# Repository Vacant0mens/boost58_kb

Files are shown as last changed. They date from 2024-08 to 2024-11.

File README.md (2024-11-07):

# boost58_kb
 
This layout was given this name because its shape looks similar to the boost arrows in racetrack video games.

# Introduction
I designed this board because I couldn't find any options that fit my requirements for a custom key board, which were:
1. completely reversible circuit board (for a split keyboard)
2. two-way UART communication between the two halves
3. compatible with Kailh Choch v2 switches (with v1 backward compatability)
4. hotswap switch sockets
5. staggered column layout (including a stagger for the outer-pinky column, and inner-index column)
6. 4 finger rows, plus only one thumb row
7. per-key and underglow RGB lights
8. anti-ghosting diodes
9.  promicro-style MCU
10. at least 1 rotary encoder per-side
11. reset button
12. power switch (optional)

I designed this with the intention of making it my dream keyboard, but also available and accessible to others. I am open to suggestions and PR's.

# Build Progress

## v0.1
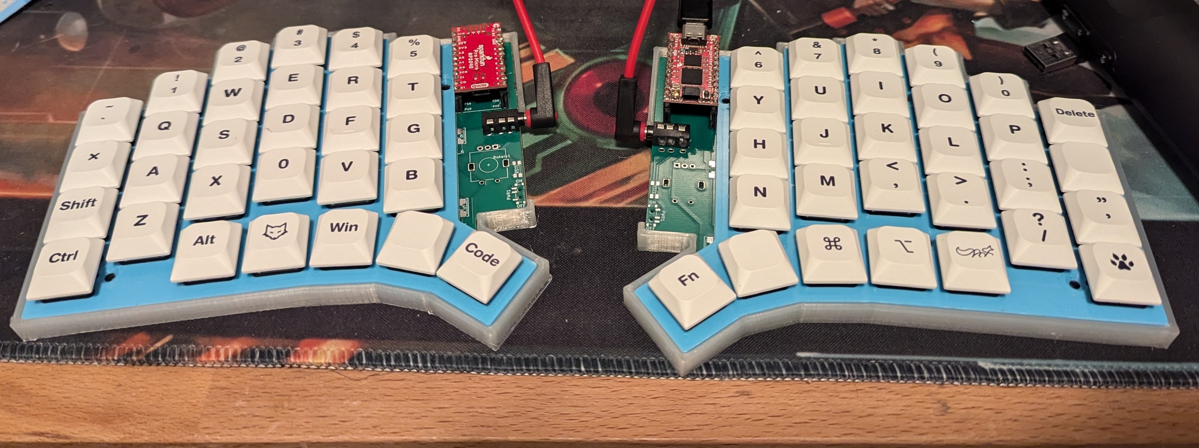
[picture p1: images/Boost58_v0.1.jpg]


## Original Top Layout
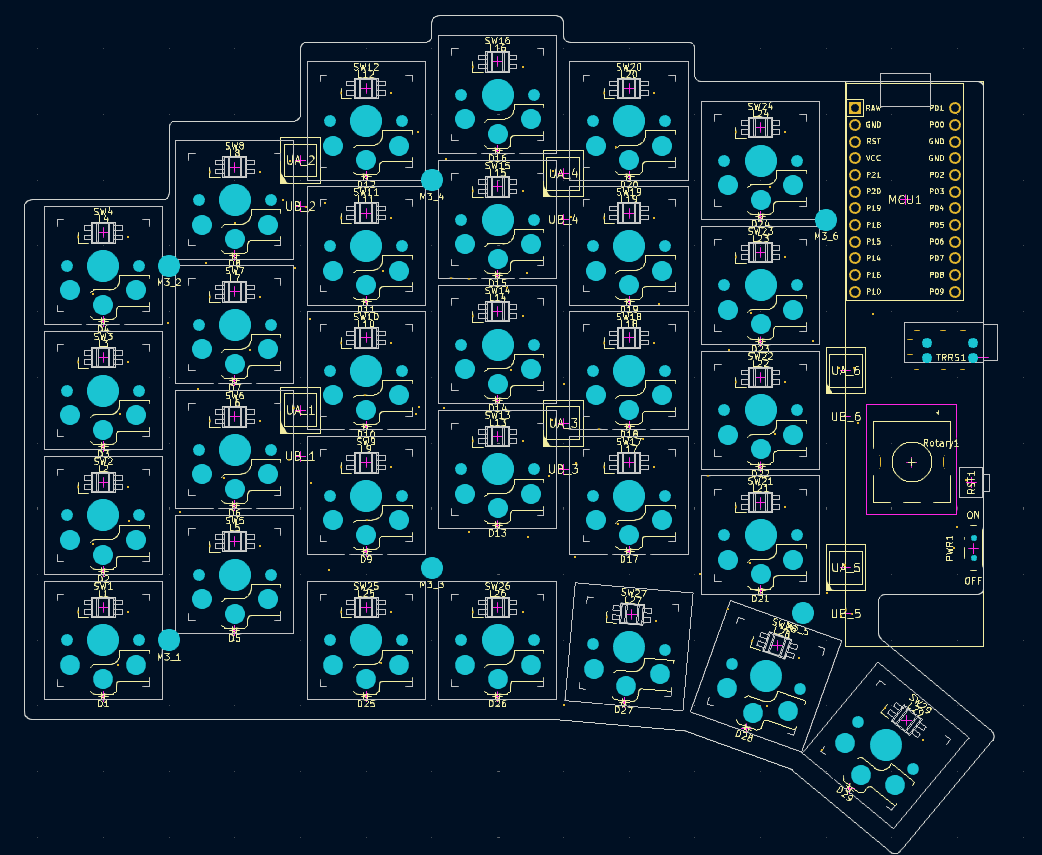
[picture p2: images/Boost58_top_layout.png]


# Thanks
Thanks to [ergogen](https://github.com/ergogen/ergogen) for the base software to be able to create this, and [ceoloide](https://github.com/ceoloide/ergogen-footprints) for the footprints and examples.

# Buy Me a Coffee
[@Vacant0mens](https://buymeacoffee.com/vacan0mens)

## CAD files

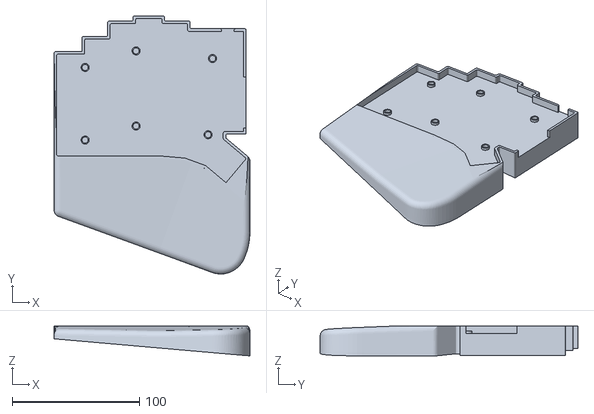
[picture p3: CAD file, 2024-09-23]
ergogen/output/pcbs/Steps and STLs/FullCase_LoweredAngle+AttachedRest.stl
153.7 x 202.6 x 23.4

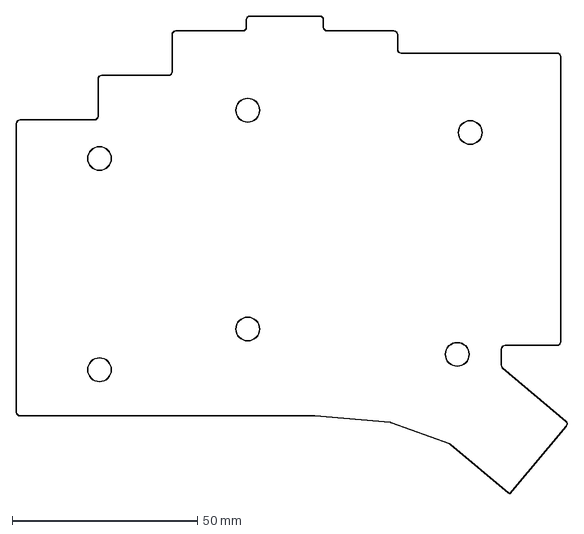
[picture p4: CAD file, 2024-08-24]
ergogen/output/outlines/bottom_plate.dxf
148.6 x 128.9 mm

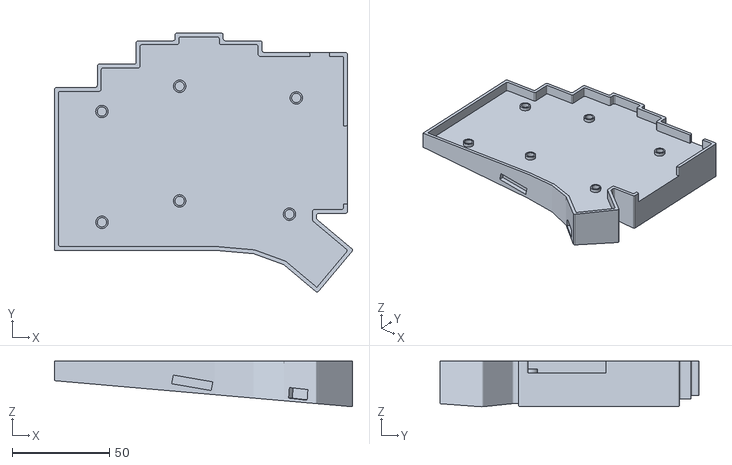
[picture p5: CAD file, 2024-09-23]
ergogen/output/pcbs/Steps and STLs/BottomCase_Tilted.stl
153.3 x 133.3 x 23.4

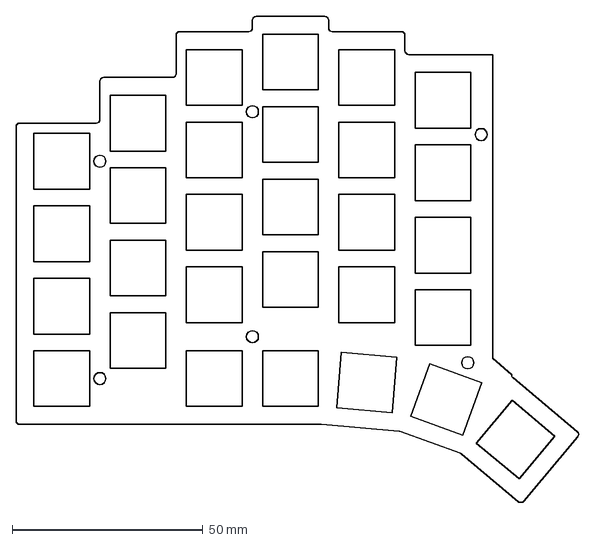
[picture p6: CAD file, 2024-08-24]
ergogen/output/outlines/spacer_plate.dxf
147.7 x 127.5 mm

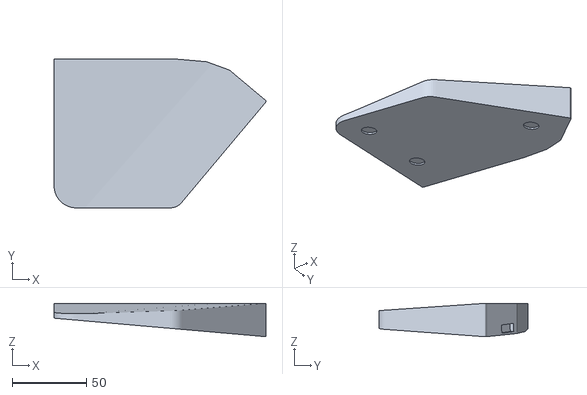
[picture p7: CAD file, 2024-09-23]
ergogen/output/pcbs/Steps and STLs/WristRest_Tilted.stl
142.5 x 100.0 x 22.5

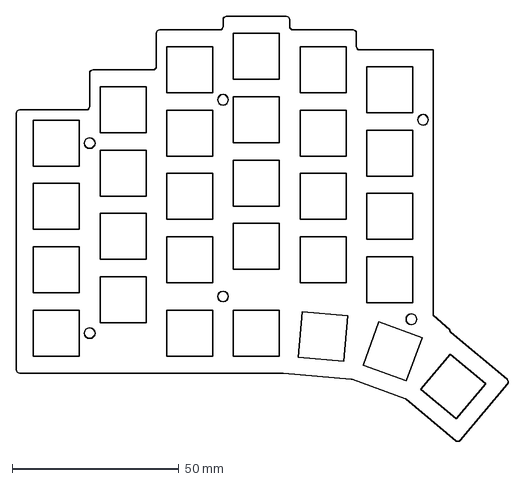
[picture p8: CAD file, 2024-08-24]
ergogen/output/outlines/top_plate.dxf
147.7 x 127.5 mm

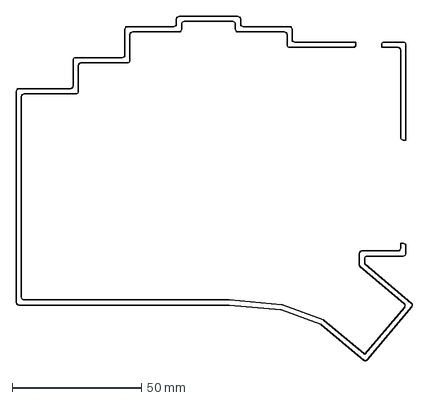
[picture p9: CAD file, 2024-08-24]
ergogen/output/outlines/panel_wall.dxf
153.4 x 133.3 mm

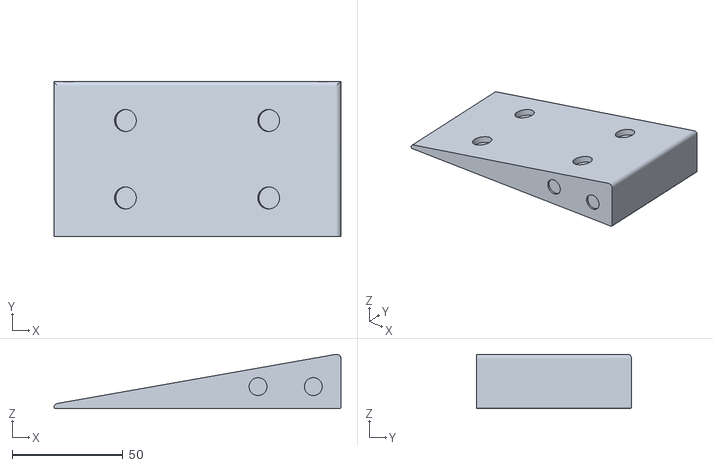
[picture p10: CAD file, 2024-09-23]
ergogen/output/pcbs/Steps and STLs/TentWedge.stl
129.8 x 70.0 x 24.6

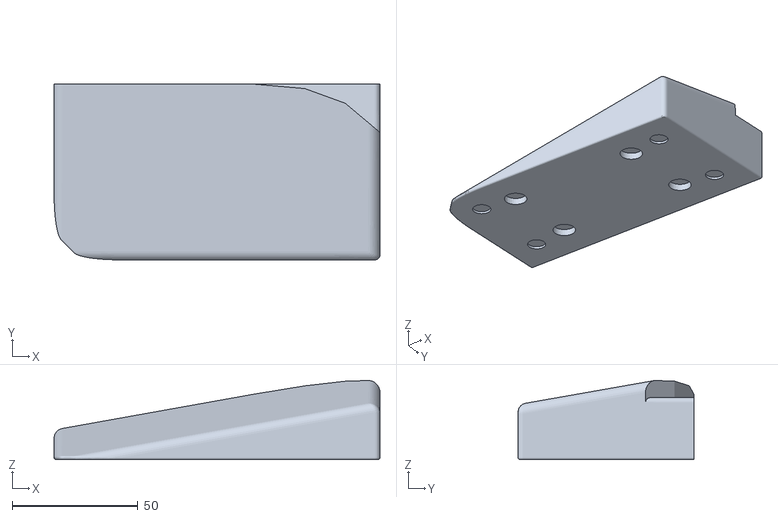
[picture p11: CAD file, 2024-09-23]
ergogen/output/pcbs/Steps and STLs/WristRest.stl
129.8 x 70.0 x 31.5

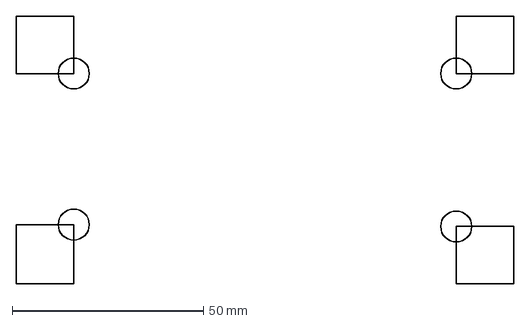
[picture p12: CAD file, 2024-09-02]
ergogen/output/pcbs/Steps and STLs/WristRest_BottomGrips.dxf
130.0 x 70.0 mm

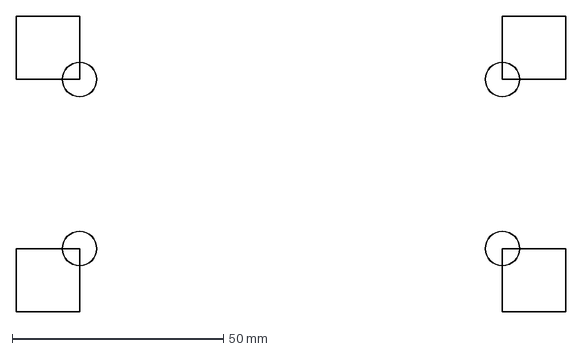
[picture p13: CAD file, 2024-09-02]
ergogen/output/pcbs/Steps and STLs/Wedge_BottomGrips.dxf
130.0 x 70.0 mm

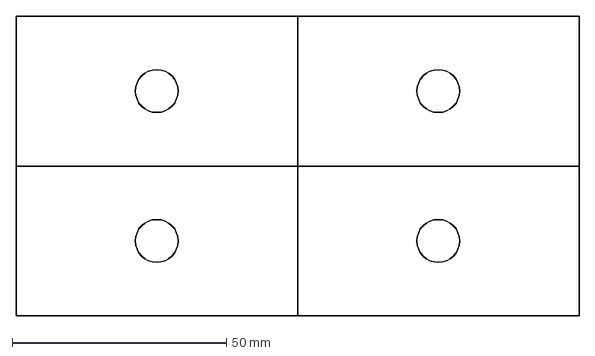
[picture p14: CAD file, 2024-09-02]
ergogen/output/pcbs/Steps and STLs/Wedge_TopMagnets.dxf
131.5 x 70.0 mm

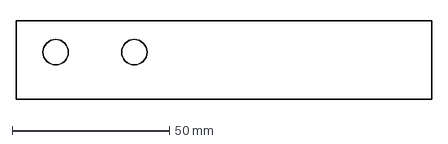
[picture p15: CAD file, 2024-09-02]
ergogen/output/pcbs/Steps and STLs/WallHoles_RestWedgeConnector.dxf
132.0 x 25.0 mm

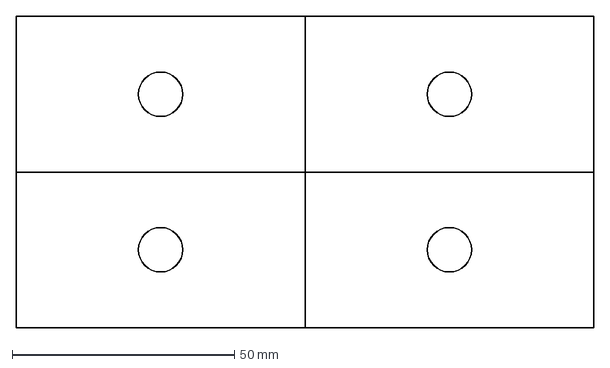
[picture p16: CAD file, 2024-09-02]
ergogen/output/pcbs/Steps and STLs/WristRestBottom.dxf
130.0 x 70.0 mm

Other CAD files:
ergogen/output/pcbs/Steps and STLs/WedgeBottom.dxf
ergogen/output/pcbs/Steps and STLs/BottomCase v3.stl
ergogen/output/pcbs/Steps and STLs/TopPlate v2.stl
ergogen/output/pcbs/Steps and STLs/key_plate v4.stl
ergogen/output/outlines/screw_posts.dxf
ergogen/output/pcbs/Steps and STLs/BottomCase v2.stl
ergogen/output/pcbs/Steps and STLs/bottom_case v3.stl
ergogen/output/pcbs/Steps and STLs/bottom_case v4.stl
ergogen/output/pcbs/Steps and STLs/key_plate v3.stl

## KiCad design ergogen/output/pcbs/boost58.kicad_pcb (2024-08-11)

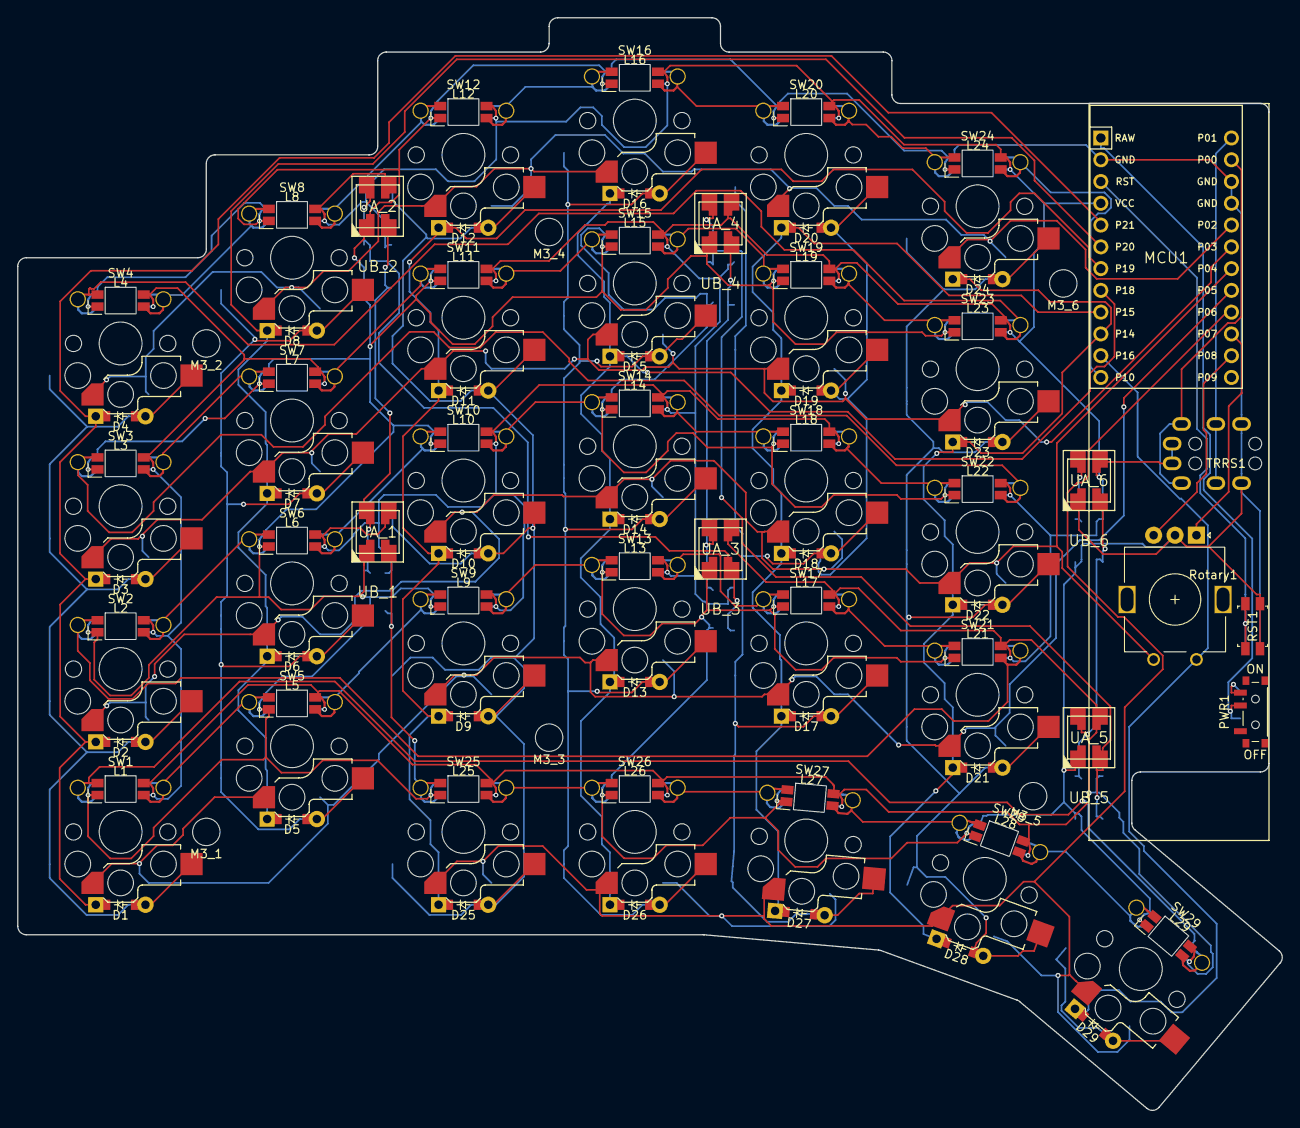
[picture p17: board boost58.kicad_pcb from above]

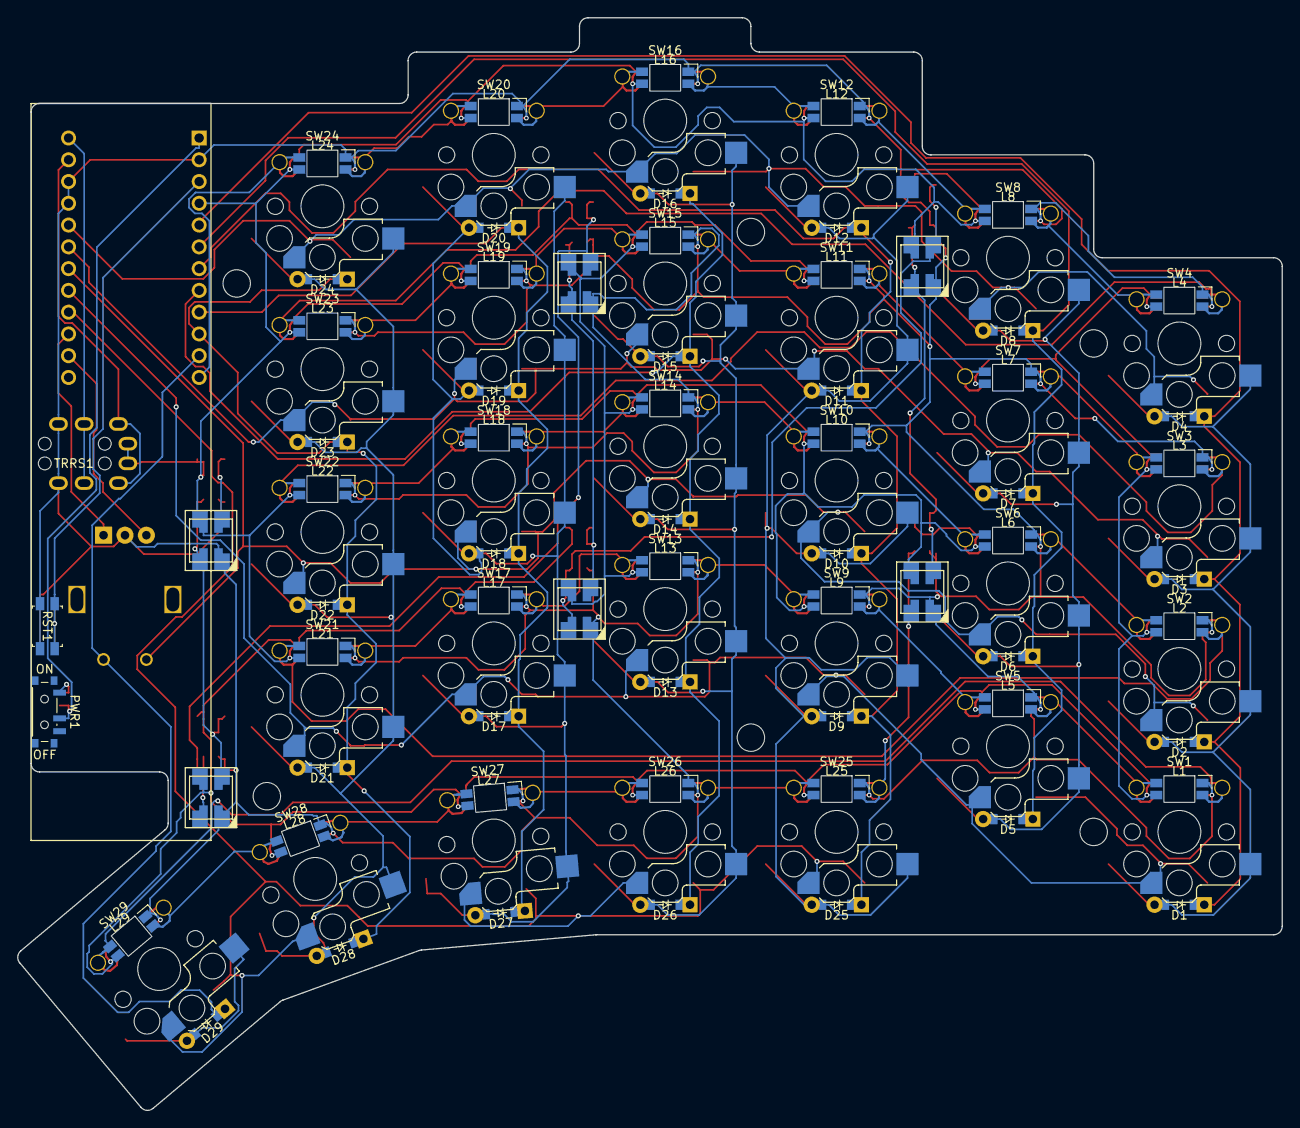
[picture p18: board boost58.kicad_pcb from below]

Board: 2 copper layers, 147.5 x 127.5 mm, 110 parts (87 on the bottom side), 64 nets.

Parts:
D1, D2, D3, D4, D5, D6, D7, D8, D9, D10, D11, D12, D13, D14, D15, D16, D17, D18, D19, D20, D21, D22, D23, D24, D25, D26, D27, D28, D29: ${REFERENCE}; diode_tht_sod123
L1, L2, L3, L4, L5, L6, L7, L8, L9, L10, L11, L12, L13, L14, L15, L16, L17, L18, L19, L20, L21, L22, L23, L24, L25, L26, L27, L28, L29: ${REFERENCE}; led_SK6812mini-e (per-key, reversible)
M3_1, M3_2, M3_3, M3_4, M3_5, M3_6: mounting_hole_npth
MCU1: ProMicro
PWR1: power_switch_smd_side
RST1: reset_switch_smd_side
Rotary1: rotary_encoder
SW1, SW2, SW3, SW4, SW5, SW6, SW7, SW8, SW9, SW10, SW11, SW12, SW13, SW14, SW15, SW16, SW17, SW18, SW19, SW20, SW21, SW22, SW23, SW24, SW25, SW26, SW27, SW28, SW29: ${REFERENCE}; switch_choc_v1_v2
TRRS1: TRRS-PJ-320A-dual
UA_1, UA_2, UA_3, UA_4, UA_5, UA_6: WS2812B
UB_1, UB_2, UB_3, UB_4, UB_5, UB_6: WS2812B

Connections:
BAT_P: PWR1.1, PWR1.3
DP14: D21.2, D22.2, D23.2, D24.2, D28.2, SW21.2, SW22.2, SW23.2, SW24.2, SW28.2
DP15: D17.2, D18.2, D19.2, D20.2, D27.2, SW17.2, SW18.2, SW19.2, SW20.2, SW27.2
DP16: D29.2, SW29.2
DP18: D13.2, D14.2, D15.2, D16.2, D26.2, SW13.2, SW14.2, SW15.2, SW16.2, SW26.2
DP19: D9.2, D10.2, D11.2, D12.2, D25.2, SW9.2, SW10.2, SW11.2, SW12.2, SW25.2
DP20: D5.2, D6.2, D7.2, D8.2, SW5.2, SW6.2, SW7.2, SW8.2
DP21: D1.2, D2.2, D3.2, D4.2, SW1.2, SW2.2, SW3.2, SW4.2
GND: L1.3, L2.3, L3.3, L4.3, L5.3, L6.3, L7.3, L8.3, L9.3, L10.3, L11.3, L12.3, L13.3, L14.3, L15.3, L16.3, L17.3, L18.3, L19.3, L20.3, L21.3, L22.3, L23.3, L24.3, L25.3, L26.3, L27.3, L28.3, L29.3, MCU1.2, MCU1.15, MCU1.16, RST1.1, RST1.3, Rotary1.C, TRRS1.4, UA_1.3, UA_1.33, UA_2.3, UA_2.33, UA_3.3, UA_3.33, UA_4.3, UA_4.33, UA_5.3, UA_5.33, UA_6.3, UA_6.33, UB_1.3, UB_1.33, UB_2.3, UB_2.33, UB_3.3, UB_3.33, UB_4.3, UB_4.33, UB_5.3, UB_5.33, UB_6.3, UB_6.33
P0: MCU1.14, TRRS1.2
P1: MCU1.13, TRRS1.3
P2: MCU1.17, SW4.1, SW8.1, SW12.1, SW16.1, SW20.1, SW24.1
P3: MCU1.18, SW3.1, SW7.1, SW11.1, SW15.1, SW19.1, SW23.1
P4: MCU1.19, Rotary1.2, SW2.1, SW6.1, SW10.1, SW14.1, SW18.1, SW22.1
P5: MCU1.20, SW1.1, SW5.1, SW9.1, SW13.1, SW17.1, SW21.1
P6: MCU1.21, SW25.1, SW26.1, SW27.1, SW28.1, SW29.1
P7: MCU1.22, Rotary1.A
P8: MCU1.23, Rotary1.B
P10: L24.2, MCU1.12
P10u01: UA_1.2, UA_1.22, UA_2.4, UA_2.44, UB_1.2, UB_1.22, UB_2.4, UB_2.44
P10u02: UA_2.2, UA_2.22, UA_3.4, UA_3.44, UB_2.2, UB_2.22, UB_3.4, UB_3.44
P10u03: UA_3.2, UA_3.22, UA_4.4, UA_4.44, UB_3.2, UB_3.22, UB_4.4, UB_4.44
P10u04: UA_4.2, UA_4.22, UA_5.4, UA_5.44, UB_4.2, UB_4.22, UB_5.4, UB_5.44
P10u05: UA_5.2, UA_5.22, UA_6.4, UA_6.44, UB_5.2, UB_5.22, UB_6.4, UB_6.44
P10u06: UA_6.2, UA_6.22, UB_6.2, UB_6.22
P14: D21.1, D22.1, D23.1, D24.1, D28.1, MCU1.10
P15: D17.1, D18.1, D19.1, D20.1, D27.1, MCU1.9
P16: D29.1, MCU1.11, Rotary1.1
P18: D13.1, D14.1, D15.1, D16.1, D26.1, MCU1.8
P19: D9.1, D10.1, D11.1, D12.1, D25.1, MCU1.7
P20: D5.1, D6.1, D7.1, D8.1, MCU1.6
P21: D1.1, D2.1, D3.1, D4.1, MCU1.5
P1001: L25.4, UA_1.4, UA_1.44, UB_1.4, UB_1.44
P1002: L25.2, L26.4
P1003: L26.2, L27.4
P1004: L27.2, L28.4
P1005: L28.2, L29.4
P1010: L1.4, L29.2
P1011: L1.2, L5.4
P1012: L5.2, L9.4
P1013: L9.2, L13.4
P1014: L13.2, L17.4
P1015: L17.2, L21.4
P1020: L2.4, L21.2
P1021: L2.2, L6.4
P1022: L6.2, L10.4
P1023: L10.2, L14.4
P1024: L14.2, L18.4
P1025: L18.2, L22.4
P1030: L3.4, L22.2
P1031: L3.2, L7.4
P1032: L7.2, L11.4
P1033: L11.2, L15.4
P1034: L15.2, L19.4
P1035: L19.2, L23.4
P1040: L4.4, L23.2
P1041: L4.2, L8.4
P1042: L8.2, L12.4
P1043: L12.2, L16.4
P1044: L16.2, L20.4
P1045: L20.2, L24.4
RAW: MCU1.1, PWR1.2
RST: MCU1.3, RST1.2, RST1.4
VCC: L1.1, L2.1, L3.1, L4.1, L5.1, L6.1, L7.1, L8.1, L9.1, L10.1, L11.1, L12.1, L13.1, L14.1, L15.1, L16.1, L17.1, L18.1, L19.1, L20.1, L21.1, L22.1, L23.1, L24.1, L25.1, L26.1, L27.1, L28.1, L29.1, MCU1.4, TRRS1.1, UA_1.1, UA_1.11, UA_2.1, UA_2.11, UA_3.1, UA_3.11, UA_4.1, UA_4.11, UA_5.1, UA_5.11, UA_6.1, UA_6.11, UB_1.1, UB_1.11, UB_2.1, UB_2.11, UB_3.1, UB_3.11, UB_4.1, UB_4.11, UB_5.1, UB_5.11, UB_6.1, UB_6.11

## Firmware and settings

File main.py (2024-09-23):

from kb_boost58 import Boost58Keyboard
from kmk.keys import KC
from kmk.modules.layers import Layers
from kmk.modules.sticky_mod import StickyMod
from kmk.modules.oneshot import OneShot
from kmk.modules.encoder import EncoderHandler
from kmk.extensions.media_keys import MediaKeys


# keyboard = HandwireKeyboard()
keyboard = Boost58Keyboard()

# keyboard.debug_enabled = False
keyboard.debug_enabled = True
keyboard.debug("Keyboard starting...")
keyboard.modules.append(Layers())
keyboard.modules.append(StickyMod())
keyboard.modules.append(OneShot())
keyboard.extensions.append(MediaKeys())

keyboard.debug("Setting custom keys...")

SPC = KC.SPC
setattr(KC, 'NOT_SET', KC.NO) # key not set
setattr(KC, 'COPY', KC.LCTL(KC.C)) # Copy
setattr(KC, 'PSTE', KC.LCTL(KC.V)) # Paste
setattr(KC, 'CUT', KC.LCTL(KC.X)) # Cut
setattr(KC, 'UNDO', KC.LCTL(KC.Z)) # Undo
setattr(KC, 'REDO', KC.LCTL(KC.Y)) # Undo
setattr(KC, 'SAVE', KC.LCTL(KC.S)) # Save
setattr(KC, 'SEL_ALL', KC.LCTL(KC.A)) # Select All
setattr(KC, 'LT', KC.LCTL(KC.LABK)) # <
setattr(KC, 'GT', KC.LCTL(KC.RABK)) # >
setattr(KC, 'CTL_SHFT_N', KC.LCTL(KC.LSFT(KC.N)))
setattr(KC, 'PLAYPAUSE', KC.MEDIA_PLAY_PAUSE)
setattr(KC, 'CTL_F5', KC.LCTL(KC.F5))
setattr(KC, 'AUTOFMT', KC.LALT(KC.LSFT(KC.F))) # VSCode AutoFormat
setattr(KC, 'COMMENT', KC.LCTRL(KC.SLSH)) # VSCode Comment Line Toggle
setattr(KC, 'xxxxxxxxxx', KC.NO) # Not a key

keyboard.debug("Custom keys set. Setting keymap...")


keyboard.keymap = [
    [  # 0 - Qwerty
        KC.GRV,        KC.N1,         KC.N2,         KC.N3,         KC.N4,         KC.N5,
                                                                    KC.xxxxxxxxxx, KC.xxxxxxxxxx, KC.N6,         KC.N7,         KC.N8,         KC.N9,         KC.N0,         KC.BSPC,
        KC.TAB,        KC.Q,          KC.W,          KC.E,          KC.R,          KC.T,
                                                                    KC.xxxxxxxxxx, KC.xxxxxxxxxx, KC.Y,          KC.U,          KC.I,          KC.O,          KC.P,          KC.BSLASH,
        KC.LSFT,       KC.A,          KC.S,          KC.D,          KC.F,          KC.G,
                                                                    KC.xxxxxxxxxx, KC.xxxxxxxxxx, KC.H,          KC.J,          KC.K,          KC.L,          KC.SCLN,       KC.QUOT,
        KC.LCTL,       KC.Z,          KC.X,          KC.C,          KC.V,          KC.B,
                                                                    KC.xxxxxxxxxx, KC.xxxxxxxxxx, KC.N,          KC.M,          KC.COMM,       KC.DOT,        KC.SLSH,       KC.ENT,
        KC.xxxxxxxxxx,
        KC.xxxxxxxxxx,
                       KC.LALT,       KC.LCTL,       KC.SPC,        KC.MO(2),      KC.MO(1),      KC.MO(1),      KC.SPC,        KC.LALT,       KC.LGUI,       KC.TG(2),
        KC.xxxxxxxxxx,
        KC.xxxxxxxxxx,
    ],
    [  # 1 - Nav, Symbols
        KC.ESC,        KC.LCTL(KC.U), KC.F9,         KC.F10,        KC.F11,        KC.F12,
                                                                    KC.xxxxxxxxxx, KC.xxxxxxxxxx, KC.NOT_SET,    KC.NOT_SET,    KC.NOT_SET,    KC.LCBR,       KC.RCBR,       KC.DEL,
        KC.F8,         KC.LCTL(SPC),  KC.CTL_F5,     KC.F5,         KC.F2,         KC.F1,
                                                                    KC.xxxxxxxxxx, KC.xxxxxxxxxx, KC.TAB,        KC.HOME,       KC.UP,         KC.END,        KC.LBRC,       KC.RBRC,
        KC.PSCR,       KC.COPY,       KC.SAVE,       KC.LCTL(KC.N), KC.LCTL(KC.F), KC.UNDO,
                                                                    KC.xxxxxxxxxx, KC.xxxxxxxxxx, KC.BSLS,       KC.LEFT,       KC.DOWN,       KC.RGHT,       KC.SCLN,       KC.QUOT,
        KC.CUT,        KC.PSTE,       KC.SEL_ALL,    KC.CTL_SHFT_N, KC.LCTL(KC.H), KC.REDO,
                                                                    KC.xxxxxxxxxx, KC.xxxxxxxxxx, KC.NOT_SET,    KC.NOT_SET,    KC.NOT_SET,    KC.LABK,       KC.RABK,       KC.MINUS,
        KC.xxxxxxxxxx,
        KC.xxxxxxxxxx,
                       KC.PLAYPAUSE,  KC.LGUI(KC.I), KC.LGUI(KC.L), KC.LSFT,       KC.TRNS,       KC.TRNS,       KC.SPC,        KC.COMMENT,    KC.AUTOFMT,    KC.MUTE,
        KC.xxxxxxxxxx,
        KC.xxxxxxxxxx,
    ],
    [  # 2 - Media, HotKeys (Pwsh, VSCode), NumPad/10-key
        KC.NOT_SET,    KC.NOT_SET,    KC.NOT_SET,    KC.NOT_SET,    KC.NOT_SET,    KC.NOT_SET,
                                                                    KC.xxxxxxxxxx, KC.xxxxxxxxxx, KC.NOT_SET,    KC.NOT_SET,    KC.NOT_SET,    KC.LPRN,       KC.RPRN,       KC.DEL,
        KC.NOT_SET,    KC.NOT_SET,    KC.NOT_SET,    KC.NOT_SET,    KC.NOT_SET,    KC.NOT_SET,
                                                                    KC.xxxxxxxxxx, KC.xxxxxxxxxx, KC.NOT_SET,    KC.N7,         KC.N8,         KC.N9,         KC.MINUS,      KC.PLUS,
        KC.NOT_SET,    KC.NOT_SET,    KC.NOT_SET,    KC.NOT_SET,    KC.NOT_SET,    KC.NOT_SET,
                                                                    KC.xxxxxxxxxx, KC.xxxxxxxxxx, KC.NOT_SET,    KC.N4,         KC.N5,         KC.N6,         KC.UNDS,       KC.EQUAL,
        KC.NOT_SET,    KC.NOT_SET,    KC.NOT_SET,    KC.NOT_SET,    KC.NOT_SET,    KC.NOT_SET,
                                                                    KC.xxxxxxxxxx, KC.xxxxxxxxxx, KC.NOT_SET,    KC.N1,         KC.N2,         KC.N3,         KC.NOT_SET,    KC.ENT,
        KC.xxxxxxxxxx,
        KC.xxxxxxxxxx,
                       KC.NOT_SET,    KC.NOT_SET,    KC.NOT_SET,    KC.TRNS,       KC.NOT_SET,    KC.NOT_SET,    KC.SPC,        KC.N0,         KC.DOT,        KC.TG(2),
        KC.xxxxxxxxxx,
        KC.xxxxxxxxxx,
    ]
]
keyboard.debug("Keymap set.")

if getattr(keyboard, 'rotary_encoder'):
    # sticky LALT
    # rotate right == hold LALT, tap TAB
    STICKY_ALT = KC.SM(KC.TAB, mod=KC.LALT)
    # rotate left == hold LALT(LSFT), tap TAB
    STICKY_SHFTALT = KC.SM(KC.LSHIFT(KC.TAB), mod=KC.LALT)

    keyboard.rotary_encoder.map = [
        [ # 0 - Qwerty
            (STICKY_ALT, STICKY_SHFTALT,), (KC.LEFT, KC.RGHT,)
        ],
        [ # 1 - Nav, Symbols
            (KC.MEDIA_PREV_TRACK, KC.MEDIA_NEXT_TRACK,), (KC.VOLD, KC.VOLU,)
        ],
        [ # 2 - Media, etc
            (KC.LSHIFT(KC.DOWN), KC.LSHIFT(KC.UP),), (KC.LSHIFT(KC.LEFT), KC.LSHIFT(KC.RGHT),)
        ]
    ]
    keyboard.debug("Encoder rotations set.")

if __name__ == '__main__':
    keyboard.go()

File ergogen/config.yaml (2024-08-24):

meta:
  engine: 4.1.0
  name: boost58
  version: 0.1
  ref: &kb_ref ""
  author: Vacant0mens
  footprint: &switch_footprint "ceoloide/switch_choc_v1_v2"
  switch:
    $extends: presets.choc
presets:
  choc:
    # Key and keycap measures
    kx: cx # spacing between key centers (X-axis)
    ky: cy # spacing between key centers (Y-axis)
    key_spread: 20 # horizontal space between columns (default: 19)
    key_padding: 19 # vertical padding between keys (deafult: 19)
    keycap_w: 17.5 # keycap width (cherry: 18, choc: 17.5)
    keycap_h: 16.5 # keycap height (cherry: 18, choc: 16.5)
    key_cutout_w: 13.8 # key cutout hole width (cherry, choc v2: 14, choc v1: 13.8)
    key_cutout_h: 13.8 # key cutout hole height (cherry, choc v2: 14, choc v1: 13.8)
    led_pos_x: 0 # Led X position relative to the switch center
    led_pos_y: 5 # Led Y position relative to the switch center
    led_rotation: 0 # Led rotation
    diode_pos_x: 0 # diode Y position relative to switch center
    diode_pos_y: -8.5 # diode Y position relative to switch center
    diode_rotation: 0 # Diode rotation
    switch_rotation: 180 # Hotswap south, led north
    screw_hole_radius: 1.6 # M3 hole; 1.6 x 2 = diameter: 3.2
    heat_insert_hole_radius: 2.4 # 2.4mm x 2 = 4.8mm (threaded inserts are 5mm)
    screw_material_radius: 3.2 # 3.2 x 2 = 6.4 diameter -- three wall lines of 0.4mm
units:
  $extends: meta.switch
points:
  zones:
    matrix:
      anchor:
        shift: [40, -120]
      key:
        tags:
        - key
        spread: key_spread
        padding: key_padding
        bind: [4, 2, 2, 2]
      #   origin: [0, -17]
      rows:
        bottom:
          row_net: P5
          led_row: 1
          led_row_next: 1
        home:
          row_net: P4
          led_row: 2
          led_row_next: 2
        top:
          row_net: P3
          led_row: 3
          led_row_next: 3
        num:
          row_net: P2
          led_row: 4
          led_row_next: 4
      columns:
        outer:
          key:
            bind: [2, 2, 4, 4]
            led_col: '0'
            led_col_next: 1
            column_net: P21
        pinky:
          key:
            led_col: 1
            led_col_next: 2
            column_net: P20
            stagger: 10
        ring:
          key:
            led_col: 2
            led_col_next: 3
            column_net: P19
            stagger: 12
        middle:
          key:
            led_col: 3
            led_col_next: 4
            column_net: P18
            stagger: 4
        index:
          key:
            led_col: 4
            led_col_next: 5
            stagger: -4
            column_net: P15
        inner:
          key:
            led_col: 5
            led_col_next: '0'
            stagger: -6
            column_net: P14
          rows:
            bottom:
              bind: [2, 10, 8, 2]
              led_row_next: '2'
            home:
              bind: [2, 26, 20, 2]
              led_row_next: '3'
            top:
              bind: [4, 26, 2, 2]
              led_row_next: '4'
            num:
              bind: [4, 26, 2, 2]
              led_row_next: ''
              led_col_next: ''
    thumb:
      anchor:
        ref: matrix_inner_bottom
        shift: [-60, -16]
      key:
        tags:
        - key
        led_row: '0'
        led_row_next: '0'
        spread: key_spread
        row_net: P6
      rows:
        only:
          padding: key_padding
      columns:
        first:
          key:
            column_net: P19
            led_col: 1
            led_col_next: 2
          rows:
            only:
              bind: [6, 2, 4, 22]
        second:
          key:
            column_net: P18
            led_col: 2
            led_col_next: 3
          rows:
            only:
              bind: [8, 4, 4, 2]
        third:
          key:
            led_col: 3
            led_col_next: 4
            stagger: -1
            splay: -5
            column_net: P15
          rows:
            only:
              bind: [8, 4, 4, 4]
        home:
          key:
            led_col: 4
            led_col_next: 5
            spread: 19
            splay: -15
            origin: [-9, -9.5]
            column_net: P14
          rows:
            only:
              bind: [4, 4, 4, 4]
        inner:
          key:
            led_col: 5
            led_col_next: '0'
            spread: 18
            splay: -20
            origin: [-9, -9.5]
            column_net: P16
          rows:
            only:
              bind: [4, 4, 4, 8]
              led_row_next: 1
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

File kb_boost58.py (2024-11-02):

import board
import os
from time import sleep
# from storage import getmount
from kmk.kmk_keyboard import KMKKeyboard
import neopixel
from kmk.utils import Debug
from kmk.scanners import DiodeOrientation
from kmk.modules.split import Split, SplitSide
from kmk.modules.layers import Layers
from kmk.modules.encoder import EncoderHandler
from kmk.extensions.media_keys import MediaKeys
from kmk.extensions.peg_oled_display import Oled,OledData,OledReactionType,OledDisplayMode
from kmk.extensions.peg_rgb_matrix import Rgb_matrix,Rgb_matrix_data


LED_POSITION_LEFT = [
     5,  6,  7,  8,  9, 10,
    11, 12, 13, 14, 15, 16,
    17, 18, 19, 20, 21, 22, 29,
    23, 24, 25, 26, 27, 28,
                30, 31, 32, 33,

                1,  0,
                3,  2,  4
]
LED_POSITION_RIGHT = [
        10,  9,  8,  7,  6,  5,
        16, 15, 14, 13, 12, 11,
    29, 22, 21, 20, 19, 18, 17,
        28, 27, 26, 25, 24, 23,
    33, 32, 31, 30,

        0,  1,
    4,  2,  3
]

OFF = [0, 0, 0]
BLACK = OFF
WHITE = [255, 255, 255]
RED = [255, 0, 0]
ORANGE = [255, 100, 0]
YELLOW = [200, 255, 0]
GREEN = [0, 255, 0]
CYAN = [0, 255, 255]
AZURE = [153, 245, 255]
BLUE = [0, 0, 255]
MAGENTA = [255, 0, 255]
PURPLE = [242, 0, 255]
TEAL = [0, 128, 128]
PINK = [255, 0, 255]


class Boost58Keyboard(KMKKeyboard):
    def __init__(self) -> None:
        super().__init__()
        self.debug = Debug(__name__)
        self.board_light = neopixel.NeoPixel(board.NEOPIXEL, 1)
        self.board_light.fill(WHITE)
        sleep(0.5)

        self.diode_orientation = DiodeOrientation.ROW2COL
        self.rgb_pixel_pin = board.D21
        self.num_pixels = 35
        self.brightness_limit = 0.35
        split_args = {
            'split_side': None,
            'data_pin': board.D0, # UART TX
            'data_pin2': board.D1,  # UART RX
            'split_flip': True,
            'use_pio': True,
            # 'uart_flip': True
        }
        self.rotary_encoder = EncoderHandler()
        self.modules.append(self.rotary_encoder)
        self.row_pins = (board.D2, board.D3, board.D4, board.D5, board.D6)
        self.col_pins = (board.D29, board.D28, board.D27,  board.D26,  board.D22, board.D20, board.D23)

        if '_LEFT' in os.listdir():
            # LEFT
            self.is_right = False
            split_args['split_side'] = SplitSide.LEFT
            self.debug("set to Left")
            self.rotary_encoder.pins = ((board.D7, board.D8, None, False,),)
            self.led_key_pos = LED_POSITION_LEFT
        elif '_RIGHT' in os.listdir():
            # RIGHT
            self.is_right = True
            split_args['split_side'] = SplitSide.RIGHT
            # split_args['uart_flip'] = True
            self.debug("set to Right")
            self.rotary_encoder.pins = ((board.D7, board.D8, None, False,),)
            self.led_key_pos = LED_POSITION_RIGHT
        else:
            while True:
                self.board_light.fill(RED)
                print("No side set.")
                sleep(1)
                print("Copy _LEFT or _RIGHT file to circuitpython drive.")
                self.board_light.fill(OFF)
                sleep(1)


        self.split = Split(**split_args)
        self.modules.append(self.split)

        self.board_light.fill(ORANGE)
        self.debug("Side set.")
        # sleep(0.5)
        
        self._set_rgb_matrix()
        # self._set_oled()

        self.board_light.fill(BLUE)
        self.debug("Setup done.")
        # sleep(0.5)
        self.board_light.fill(GREEN)
        # sleep(0.5)

    def _set_rgb_matrix(self):
        self.debug("Adding RGB.")
        lights = []
        glow = []
        for c in range(6):
            lights.append(RED) # top row
        for c in range(6):
            lights.append(ORANGE) # top-middle row
        for c in range(6):
            lights.append(YELLOW) # bottom-middle row
        for c in range(7):
            lights.append(GREEN) # bottom row
        for c in range(4):
            lights.append(BLUE) # thumb row
        for c in range(5):
            glow.append(MAGENTA) # underglow

        # self.debug("***** Lights array length:", str(len(lights)))
        # self.debug("***** Underglow array length:", str(len(glow)))
        rgb_ext = Rgb_matrix(
            ledDisplay=Rgb_matrix_data(
                keys=lights,                     
                underglow=glow
            ),
            split=False, rightSide=self.is_right
        )
        self.extensions.append(rgb_ext)

    # def _set_oled(self):
    #     self.debug("Adding OLED extension")
    #     self.SCL = board.D3
    #     self.SDA = board.D2
    #     oled_ext = Oled(
    #         OledData(
    #             corner_one={0:OledReactionType.STATIC,1:["layer"]},
    #             corner_two={0:OledReactionType.LAYER,1:["1","2","3","4"]},
    #             corner_three={0:OledReactionType.LAYER,1:["base","raise","lower","adjust"]},
    #             corner_four={0:OledReactionType.LAYER,1:["qwerty","nums","shifted","leds"]}
    #         )
    #     )
    #     # self.extensions.append(oled_ext)

if __name__ == '__main__':
    keyboard = Boost58Keyboard()
    keyboard.go()

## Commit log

2024-08-11 pulled and modified footprints from ceoloide's footprints repo (PR incoming later)
2024-08-11 generated KiCad PCB's and outlines with ergogen
    [bottom_plate.dxf, first.dxf, keycap_outline.dxf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]
2024-08-11 autorouted and imported session to PCB
2024-08-11 exported STEP files for bottom, top, and spacer plates, and converted them to STL's for printing
    [spacer_plate.step, spacer_plate.stl, top_bottom_plate.step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]
2024-08-11 generated gerber and drill files (and put them in zip files for later use)
    [spacer_plate-B_Cu.gbr, spacer_plate-B_Mask.gbr, spacer_plate-B_Paste.gbr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]
2024-08-11 updated ergogen config to have correct name in output files
    [config.yaml]
2024-08-11 renamed files to correct name instead of generic/prototype name
    [boost58-B_Cu.gbr, boost58-B_Fab.gbr, boost58-B_Mask.gbr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]
2024-08-20 reduced binding around inner_home key
    [config.yaml]
2024-08-20 removed commented lines, refactored outline references to short syntax, made panel and keycap_outline internal-only
    [config.yaml]
2024-08-20 removed PCB plates in favor of using the outlines as sketches in Fusion to make the case
2024-08-20 added keycap outlines to pcb silkscreens
2024-08-20 added a wall outline for the wall of the bottom case
2024-08-20 added material around the screw holes to support PCB
2024-08-20 increased _switch_spacer_cutouts size for better printability
2024-08-20 changed screw posts to be bigger, for heat-set threaded inserts
2024-08-20 changed size of top_plate cutout for MCU and Rotary Encoder
2024-08-20 created v0.1 zip file - main PCB has been made from these files
2024-08-20 removed excess outline and pcb files (already removed from config.yml)
    [first.dxf, panel.dxf, raw.dxf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]
2024-08-20 re-generated files for drawings (to make a new case in Fusion)
    [panel_wall.dxf, screw_posts.dxf, spacer_plate.dxf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]
2024-08-20 un-did changes to top-plate cutout and binding on inner home key (will be part of v0.2 branch)
    [config.yaml]
2024-08-20 moved power switch back to match v0.1 until v0.2 is ready for PCB creation and new case
2024-08-20 added STL's for bottom case and top/key plate
    [bottom_case v3.stl, bottom_case v4.stl, key_plate v3.stl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]
2024-08-20 re-generated drawings
    [bottom_plate.dxf, panel_wall.dxf, screw_posts.dxf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]
2024-08-20 removed excess step files
    [spacer_plate.step, top_bottom_plate.step, top_plate.step]
2024-08-24 added cutouts in bottom case for buttons and USB port
2024-08-24 made bottom case wall slightly larger to compensate for PCB tolerances
    [config.yaml]
2024-08-24 removed keycap outline drawing file and re-generated all outlines
    [bottom_plate.dxf, keycap_outline.dxf, panel_wall.dxf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]
2024-08-24 created new STL's with Fusion from drawing files
    [BottomCase v2.stl, TopPlate v2.stl, spacer_plate.stl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]
2024-08-24 added slight updates to footprints for contributing to ceoloide/ergogen-footprints
2024-09-01 added pin to account for extra column in matrix+thumb zones
2024-09-02 exported STL and drawings from Fusion for later work with the case add-ons
    [BottomCase v3.stl, WallHoles_RestWedgeConnector.dxf, WedgeBottom.dxf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]
2024-09-23 added a wedge and wrist rest to current case design
    [TentWedge.stl, WristRest.stl]
2024-09-23 redesigned case to be unibody with wrist rest built in
    [FullCase_LoweredAngle+AttachedRest.stl]
2024-09-23 combined both case designs; lower tilt angle, built-in wedge, but with a detachable wrist rest
    [BottomCase_Tilted.stl, WristRest_Tilted.stl]
2024-09-23 switched space and layer-2 key in key layout
2024-11-02 switched UART pins, turned off uart_flip for Right
